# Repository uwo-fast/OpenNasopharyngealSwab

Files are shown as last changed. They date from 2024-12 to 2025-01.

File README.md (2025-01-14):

# Open Source Nasopharyngeal Swab and UV Curing System

This repository hosts the open-source design files, instructions, and validation results for a parametric nasopharyngeal swab and UV curing system. The designs are tailored for distributed manufacturing using accessible 3D printing technologies. Originally developed to address swab shortages during the COVID-19 pandemic, this project aims to provide a low-cost, scalable solution for clinical testing and other medical applications.

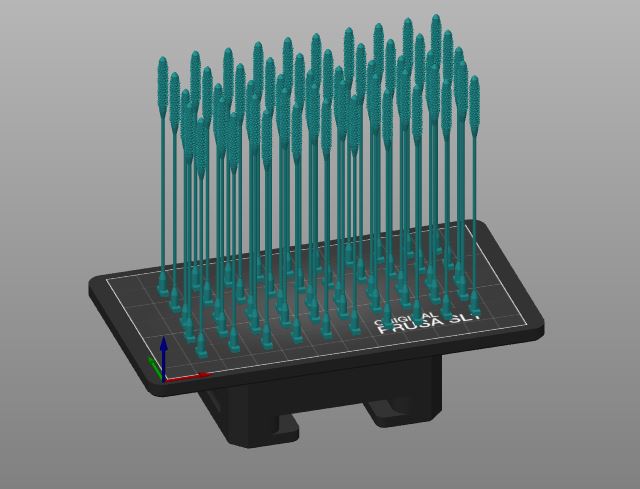
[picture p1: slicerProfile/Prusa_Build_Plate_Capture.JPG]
View of Swab on Build Plate in Slicer


## Features

- **Parametric Design:** Fully customizable in OpenSCAD to adapt swab and handle features for specific needs.
  - Tested with [github.com/CameronBrooks11/OpenSCAD-Batch-Export](https://github.com/CameronBrooks11/OpenSCAD-Batch-Export)
- **Distributed Manufacturing:** Designed for SLA 3D printers and modular UV curing systems, enabling local production with low-cost, accessible equipment.
- **Validated Performance:** Mechanical testing ensures durability and safety for clinical applications.
- **Open Source:** Licensed under GNU GPL v3.0 and CERN OHL v1.2 for maximum accessibility and collaboration.

## Cost Overview

- Nasopharyngeal Swabs:
  - Press-fit handle: ~$0.06/swab
  - Tong-style handle: ~$0.11/swab
- Modular UV Curing System: $45 total

## Included Components

1. **Swab Design Files:**
   - Parametric OpenSCAD files for the swab and handle.
   - STL files for SLA and FFF printers.
2. **UV Curing System:**
   - Design files for modular PCBs and 3D printable components.
   - Assembly instructions and parts list.

## Bill of Materials (BOM)

- **Swabs:** UV resin for swab heads and thermoplastics (e.g., PLA, PETG) for handles.
- **UV System:** Modular PCB components, UV LEDs, 3D printed brackets, and power supply.

## How to Use

### Swab Fabrication

1. Print swab heads using SLA 3D printers.
2. Print handles using FFF 3D printers.
3. Assemble and cure swabs in the UV curing system.

### UV Curing System Assembly

1. Solder PCBs and assemble the modular curing box.
2. Connect power and ensure system functionality with a multimeter.

### Validation

- Follow the provided mechanical testing protocols for tensile strength and break points.
- Conduct clinical testing in accordance with FDA or regional guidelines.

## Licensing

This project is licensed under:

- GNU General Public License (GPL) v3.0
- CERN Open Hardware License (OHL) v1.2

## Contributing

Contributions to improve the design, validation, or documentation are welcome. Please open an issue or submit a pull request.

## Citation

If you use this project in your work, please cite the original paper:  
Gallup, N., Pringle, A. M., Oberloier, S., Tanikella, N. G., & Pearce, J. M. (2020). *Parametric nasopharyngeal swab for sampling COVID-19 and other respiratory viruses: Open source design, SLA 3-D printing and UV curing system*. HardwareX, 8, e00135.

## Acknowledgments

This work was supported by the Witte Foundation and benefited from the contributions of numerous collaborators listed in the publication.

For more details, visit the [source paper](https://doi.org/10.1016/j.ohx.2020.e00135) or access original files on the [Open Science Framework (OSF)](https://osf.io/z5jgu/).

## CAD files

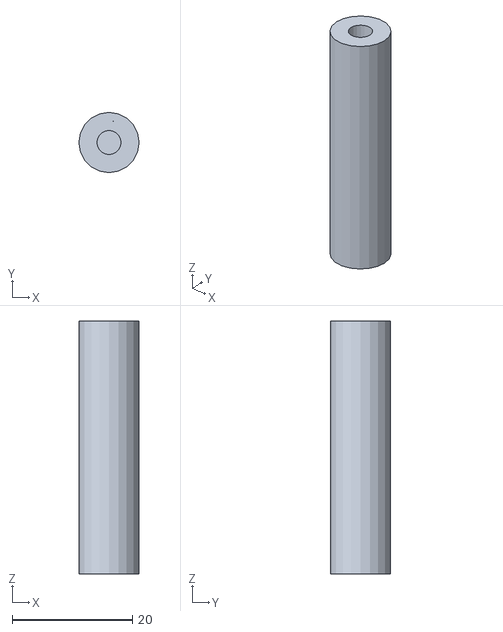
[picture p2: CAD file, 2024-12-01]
misc/durability_test_tube.stl
10.0 x 10.0 x 42.0

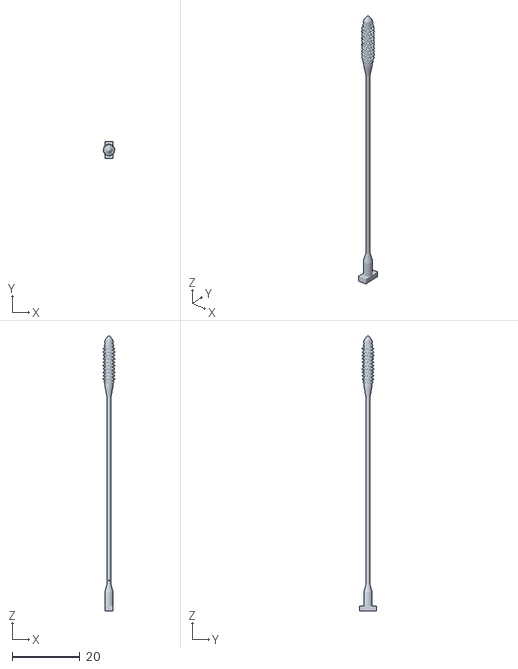
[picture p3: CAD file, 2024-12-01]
outputs/nasal_swab_bullet tip.stl
3.47 x 5.00 x 81.2

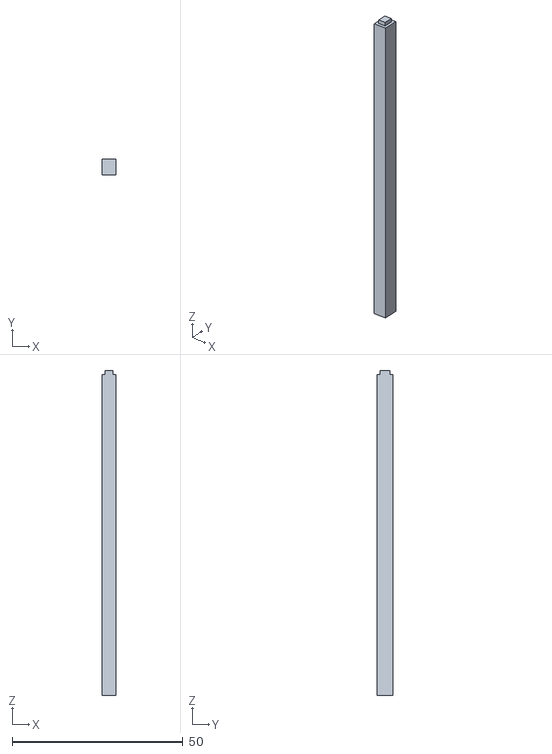
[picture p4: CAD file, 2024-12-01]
uvCuringBox/mech/legs.stl
4.00 x 4.70 x 95.1

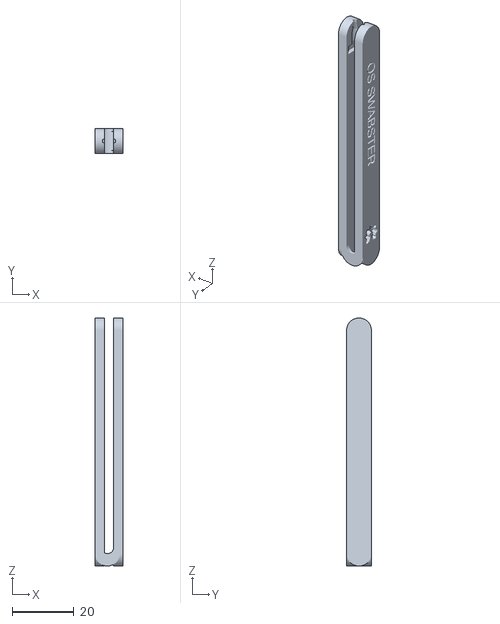
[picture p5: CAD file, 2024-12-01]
misc/tong_handle.stl
9.00 x 8.00 x 80.0

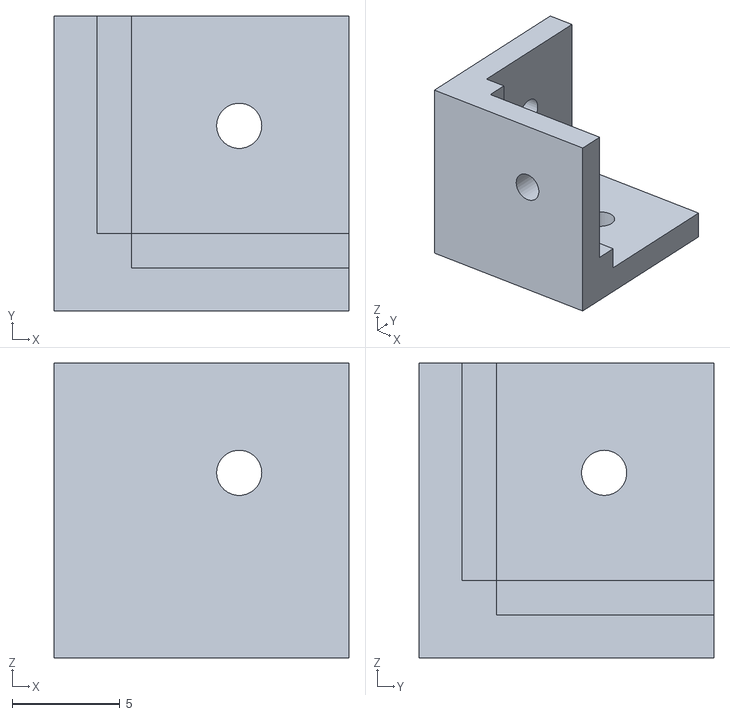
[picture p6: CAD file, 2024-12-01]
uvCuringBox/mech/corner.stl
13.7 x 13.7 x 13.7

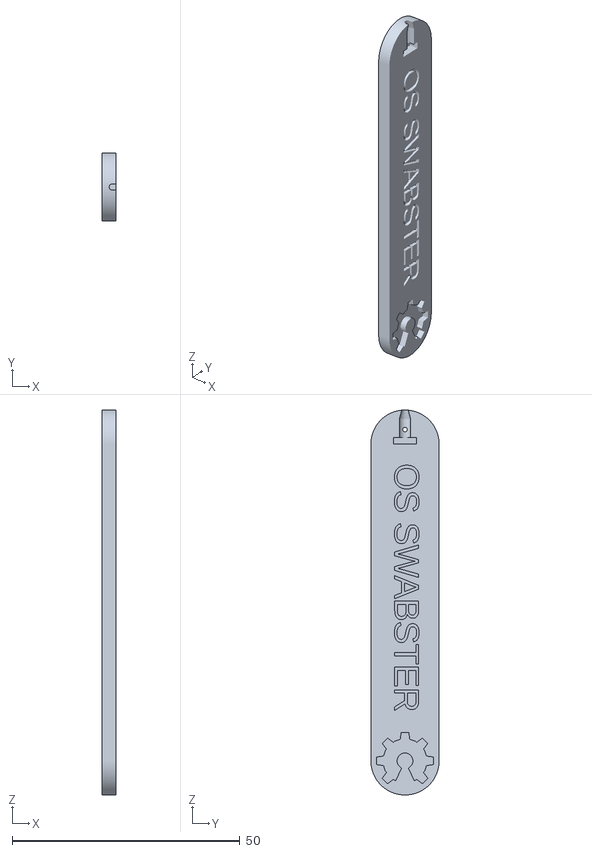
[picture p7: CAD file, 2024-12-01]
outputs/lock_handle.stl
3.00 x 15.0 x 84.5

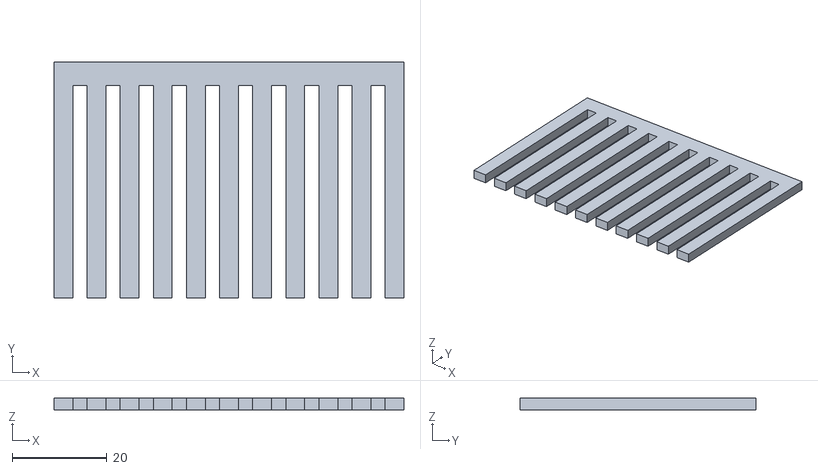
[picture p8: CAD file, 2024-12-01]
uvCuringBox/mech/top.stl
74.0 x 50.0 x 2.50

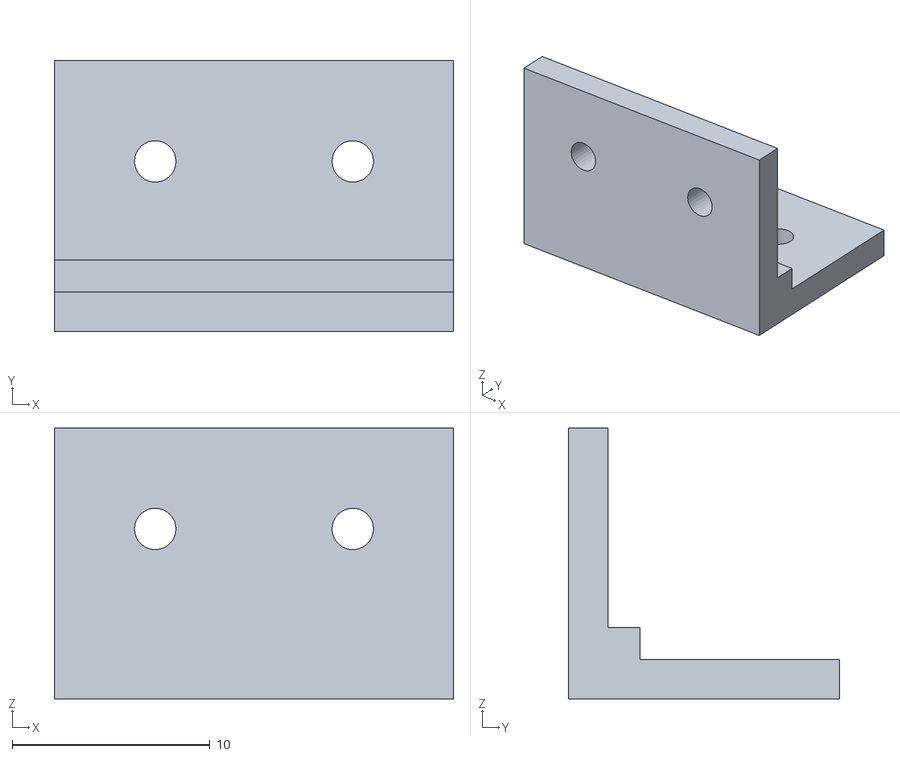
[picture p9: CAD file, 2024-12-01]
uvCuringBox/mech/edge.stl
20.2 x 13.7 x 13.7

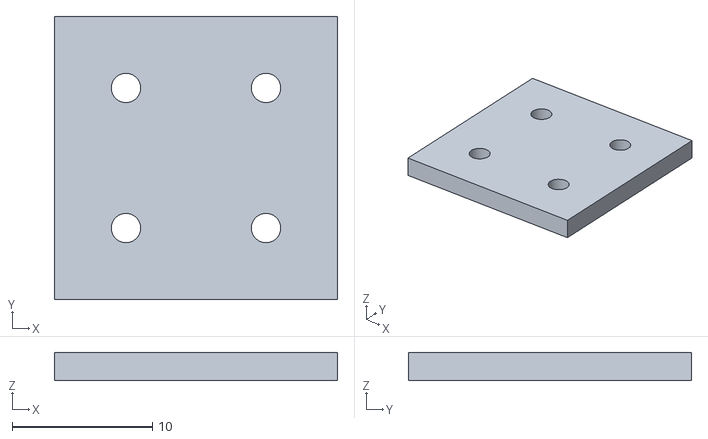
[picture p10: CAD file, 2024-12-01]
uvCuringBox/mech/plate.stl
20.2 x 20.2 x 2.00

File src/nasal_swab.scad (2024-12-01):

// OS nasal swab
// 20-4-21
// Adam Pringle
// MOST group at MTU
//
// Cameron K. Brooks
// Formatting and organizing
// FAST Research Group at UWO

// All units are in metric and mm unless otherwise specified

// Render the desired object by changing the name of the render variable
render = "nasal_swab"; // ["nasal_swab", "lock_handle", "both"]

// Tip type: Select the tip geometry type
tip_type = "bullet"; // ["bullet", "cone"]

if (render == "nasal_swab")
{
    nasal_swab();
}
else if (render == "lock_handle")
{
    lock_handle();
}
else if (render == "both")
{
    lock_handle();
    nasal_swab();
}

// Settings for contours and curve resolution
$fa = 0.5;  // minimum angle for a fragment,, recommended:0.5
$fs = 0.15; // minimum size of a fragment, recommended: 0.5 is for changing variables, 0.15 should be used for final
            // render

//[Tip settings] --------------------------------------------------------------------------------------------
tip_height = 16.25;  // Length of the tip height, recommended:16.25
tip_radius = 1.125;  // Radius of the tip body section, recommended:1.125

tip_arm_radius = 1.5;        // Max radius of the tip arms, recommended:1.5
tip_arm_thickness = .5;      // diameter of the tip arm cylinders, recommended:0.5
tip_arm_spread = .5;         // distance between layers of arms, recommended:0.5
tip_arm_count = 5;           // Number of arms per layer 360/count, recommended:3 or 5
tip_arm_rotation_angle = 90; // angle of rotation of arms layer to layer, recommended:90

tip_taper_low_height = 5; // Height of the taper region towards the body, recommended:5

tip_taper_top_height = 4; // Height of the taper region towards the top, recommended:4
tip_taper_top_R1 = 1;     // radius of top cylinder for subtraction at the top tip, recommended:1
tip_taper_bot_R2 = 1.5;   // radius of bot cylinder for subtraction at the top tip, recommended:1.5

// cone_tip
tip_point_height = 1.5;                // Height of the pointed section at the top of the tip, recommended:1
tip_point_radius_top = .25;            // radius of the top of the tip point, recommended:0.25
tip_point_radius_bot = tip_radius + 0; // radius of the bottom of the tip point, recommended:tip_radius+0.25

// bullet_tip
tip_point_radius_bullet = 1.15; // radius of the bullet tip, recommended:1.15

//[Body settings] --------------------------------------------------------------------------------------------
body_height = 55.5; // Height of the single-use body section, recommended:55.5
body_radius = 0.56; // radius of the single-use body section - match with base_taper_radius, recommended:0.56

body_breakpoint_radius = 0.175; // radius of the throughhole to ensure breaking at the weakpoint, recommended:0.1
body_breakpoint_height = 1;     // distance of breakpoint from the tapered section, recommended:1

//[base settings] --------------------------------------------------------------------------------------------
base_type = "lock";       //[spring, lock] select the base geometry type - only lock has been designed
base_height = 8;          // Height of the single-use body section, recommended:8
base_radius = 1.25;       // radius of the single-use body section, recommended:1.25
base_taper_radius = 0.56; // radius of the base taper - match with body_radius, recommended:0.56
base_taper_height = 2.5;  // length of the base height which tapers to the taper radius, recommended:2.5

base_flat_height =
    5; // length of the flat section on the bottom of the base use with spring base geometry, recommended:5
base_lock_length = 5;   // length of the L-shape locking mechanism, recommended:5
base_lock_height = 1.5; // height of the L-shape locking mechanism, recommended:1.5

//[handle settings] --------------------------------------------------------------------------------------------
handle_X_thickness = 1;             // thickness of handle under base insert in X direction, recommended:1
handle_X_width = base_radius + .75; // width of the handle section in total, recommended:base_radius+0.75
handle_Y_length = 15;               // length of the handle section, recommended:15
handle_Z_height = 85;               // handle height for gripping by people, recommended:85
handle_pin_hole_radius = .5;        // radius of the pinhole to ensure base is easy to pop, recommended:0.5

OSHW_logo_subtraction = 5;
OSHW_logo_diameter = 12.5;

handle_text_Z = -handle_Z_height * .05;
handle_text_Y = -handle_Y_length * .15;
handle_text_size = 5.5;
handle_text = "OS SWABSTER";

// module for construction of nasal_swab
module nasal_swab()
{
    color("yellow") if (tip_type == "cone")
    {

        cone_tip();
    }
    else if (tip_type == "bullet")
    {

        bullet_tip();
    }

    // color("purple")
    tip();

    color("blue") body();

    color("green") if (base_type == "spring")
    {

        spring_base();
    }
    else if (base_type == "lock")
    {

        lock_base();
    }
    // color("red")

} // end of module nasal_swab

module cone_tip()
{
    translate([ 0, 0, tip_height + tip_point_height / 2 + body_height + base_height ])
        cylinder(tip_point_height, tip_point_radius_bot, tip_point_radius_top, true);

} // end of module cone_tip

module bullet_tip()
{
    translate([ 0, 0, tip_height + tip_point_height / 2 + body_height + base_height ])

        hull()
    {
        translate([ 0, 0, tip_point_height / 2 - tip_point_radius_bullet / 2 ]) sphere(tip_point_radius_bullet / 2);

        translate([ 0, 0, -tip_point_height / 2 + tip_point_height * 0.1 ])
            cylinder(tip_point_height * 0.2, tip_point_radius_bot, tip_point_radius_bot, true);
    }
} // end of module bullet_tip

module tip()
{

    translate([ 0, 0, +body_height + base_height ])
    {

        difference()
        {
            color("purple") union()
            {
                translate([ 0, 0, tip_height / 2 ]) cylinder(tip_height, tip_radius, tip_radius, true);

                for (x = [tip_taper_low_height * .05:tip_height / (tip_arm_spread + tip_arm_thickness)]) // numb
                    translate([ 0, 0, (tip_arm_spread + tip_arm_thickness) * x - tip_arm_thickness / 2 ])
                        rotate([ 0, 0, 90 * x ]) for (x = [0:tip_height]) // # of arms on each layer
                        rotate([ 0, 0, 360 / tip_arm_count * x ])

                            hull()
                    {
                        translate([ tip_arm_radius, 0, 0 ]) sphere(tip_arm_thickness / 2);
                        translate([ -tip_arm_radius, 0, 0 ]) sphere(tip_arm_thickness / 2);
                    }
            }
            color("red")
                // top section taper towards tip tip
                translate([ 0, 0, tip_height ]) difference()
            {

                cylinder(tip_taper_top_height + .01, tip_arm_radius * 2 + .01, tip_arm_radius * 2 + .01, true);
                cylinder(tip_taper_top_height + .02, tip_taper_bot_R2, tip_taper_top_R1, true);
            }

            color("red")
                // bot section taper towards tip bottom
                translate([ 0, 0, tip_taper_low_height / 2 - tip_arm_thickness ]) difference()
            {

                cylinder(tip_taper_low_height + .01, tip_arm_radius * 2 + .01, tip_arm_radius * 2 + .01, true);
                cylinder(tip_taper_low_height + .02, body_radius, tip_arm_radius + .01, true);
            }
        }
    }
} // end of module tip

module spring_base() // bottom, blue section
{
    // taper section
    translate([ 0, 0, base_height / 2 + base_height / 2 - base_taper_height / 2 ])
        cylinder(base_taper_height, base_radius, base_taper_radius, true);

    // base section
    difference()
    {
        translate([ 0, 0, base_height / 2 - base_taper_height / 2 ])
            cylinder(base_height - base_taper_height, base_radius, base_radius, true);

        translate([ 0, base_radius, base_flat_height / 2 ])
            cube([ base_radius * 2, base_radius, base_flat_height + .01 ], true);
    }
} // end of module base

module lock_base() // bottom, blue section
{
    // taper section
    translate([ 0, 0, base_height / 2 + base_height / 2 - base_taper_height / 2 ])
        cylinder(base_taper_height, base_radius, base_taper_radius, true);

    // base section

    translate([ 0, 0, base_height / 2 - base_taper_height / 2 ])
        cylinder(base_height - base_taper_height, base_radius, base_radius, true);

    translate([ 0, 0, base_lock_height / 2 ]) cube([ base_radius * 2, base_lock_length, base_lock_height ], true);
}

module body()
{

    difference()
    {

        translate([ 0, 0, body_height / 2 + base_height ]) cylinder(body_height, body_radius, body_radius, true);

        translate([ 0, 0, 0 + base_height + body_breakpoint_height ]) rotate([ 90, 0, 0 ])
            cylinder(body_radius * 5, body_breakpoint_radius, body_breakpoint_radius, true, $fn = 15);
    }

} // end of module body
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

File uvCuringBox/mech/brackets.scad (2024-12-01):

p_tk = 2;
h_d = 2.1;
Off_X = 5;
Off_Y = 5;
b_tk = 1.6;

ext = 0.1;
$fn = 30;

module plate()
{
    translate([ 0, 0, -p_tk / 2 ]) difference()
    {
        translate([ -p_tk, -p_tk, 0 ]) cube([ (Off_X + h_d + 3) + p_tk, (Off_Y + h_d + 3) + p_tk, p_tk ]);
        translate([ Off_X, Off_Y, -ext ]) cylinder(h = p_tk + ext * 2, d = h_d);
    }
}

module p_1x2()
{
    plate();
    mirror([ 0, 1, 0 ]) plate();
}

module e_1x2()
{
    plate();
    translate([ 0, -p_tk / 2 - b_tk, p_tk / 2 + b_tk ]) rotate([ 90, 0, 0 ]) plate();
    translate([ -p_tk, -p_tk - b_tk, -p_tk / 2 ]) cube([ Off_X + h_d + 3 + p_tk, p_tk + b_tk, p_tk + b_tk ]);
}

module p_2x2()
{
    p_1x2();
    mirror([ 1, 0, 0 ]) p_1x2();
}

module e_2x2()
{
    e_1x2();
    mirror([ 1, 0, 0 ]) e_1x2();
}

module corner()
{
    plate();

    translate([ -p_tk / 2 - b_tk, 0, p_tk / 2 + b_tk ]) rotate([ 0, -90, 0 ]) plate();

    translate([ 0, -p_tk / 2 - b_tk, p_tk / 2 + b_tk ]) rotate([ 90, 0, 0 ]) plate();
    translate([ -p_tk, -p_tk - b_tk, -p_tk / 2 ]) cube([ Off_X + h_d + 3 + p_tk, p_tk + b_tk, p_tk + b_tk ]);
    translate([ -p_tk - b_tk, -p_tk, -p_tk / 2 ]) cube([ p_tk + b_tk, Off_X + h_d + 3 + p_tk, p_tk + b_tk ]);

    translate([ -p_tk - b_tk, -p_tk - b_tk, -p_tk / 2 ])
        cube([ p_tk + b_tk, p_tk + b_tk, Off_X + h_d + 3 + p_tk * 1 + b_tk ]);
}

e_2x2();

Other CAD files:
outputs/nasal_swab_cone_tip.stl

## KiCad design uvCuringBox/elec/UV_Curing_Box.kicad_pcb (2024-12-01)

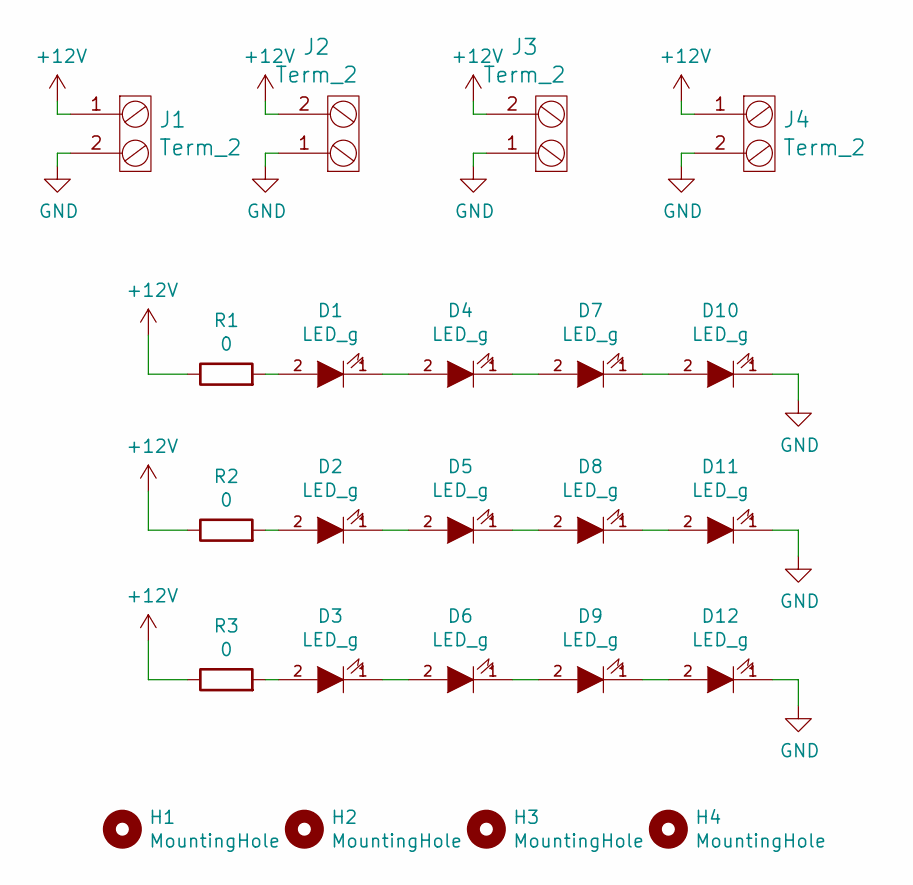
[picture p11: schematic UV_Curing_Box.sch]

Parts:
D1, D2, D3, D4, D5, D6, D7, D8, D9, D10, D11, D12: LED_g; LED-5MM; Part # C566C-GFF-CX0Y0892
H1, H2, H3, H4: MountingHole; MountingHole_2.2mm_M2
J1, J2, J3, J4: Term_2; TerminalBlock_Pheonix_MKDS1.5-2pol; Part # 1935161
R1, R2, R3: 0; R_1206_HandSoldering; Part # RC1206JR-070RL

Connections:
+12V: J1.1, J2.2, J3.2, J4.1, R1.1, R2.1, R3.1
GND: D10.1 (K), D11.1 (K), D12.1 (K), J1.2, J2.1, J3.1, J4.2
unnamed: D1.1 (K), D4.2 (A)
unnamed: D1.2 (A), R1.2
unnamed: D2.1 (K), D5.2 (A)
unnamed: D2.2 (A), R2.2
unnamed: D3.1 (K), D6.2 (A)
unnamed: D3.2 (A), R3.2
unnamed: D4.1 (K), D7.2 (A)
unnamed: D5.1 (K), D8.2 (A)
unnamed: D6.1 (K), D9.2 (A)
unnamed: D7.1 (K), D10.2 (A)
unnamed: D8.1 (K), D11.2 (A)
unnamed: D9.1 (K), D12.2 (A)

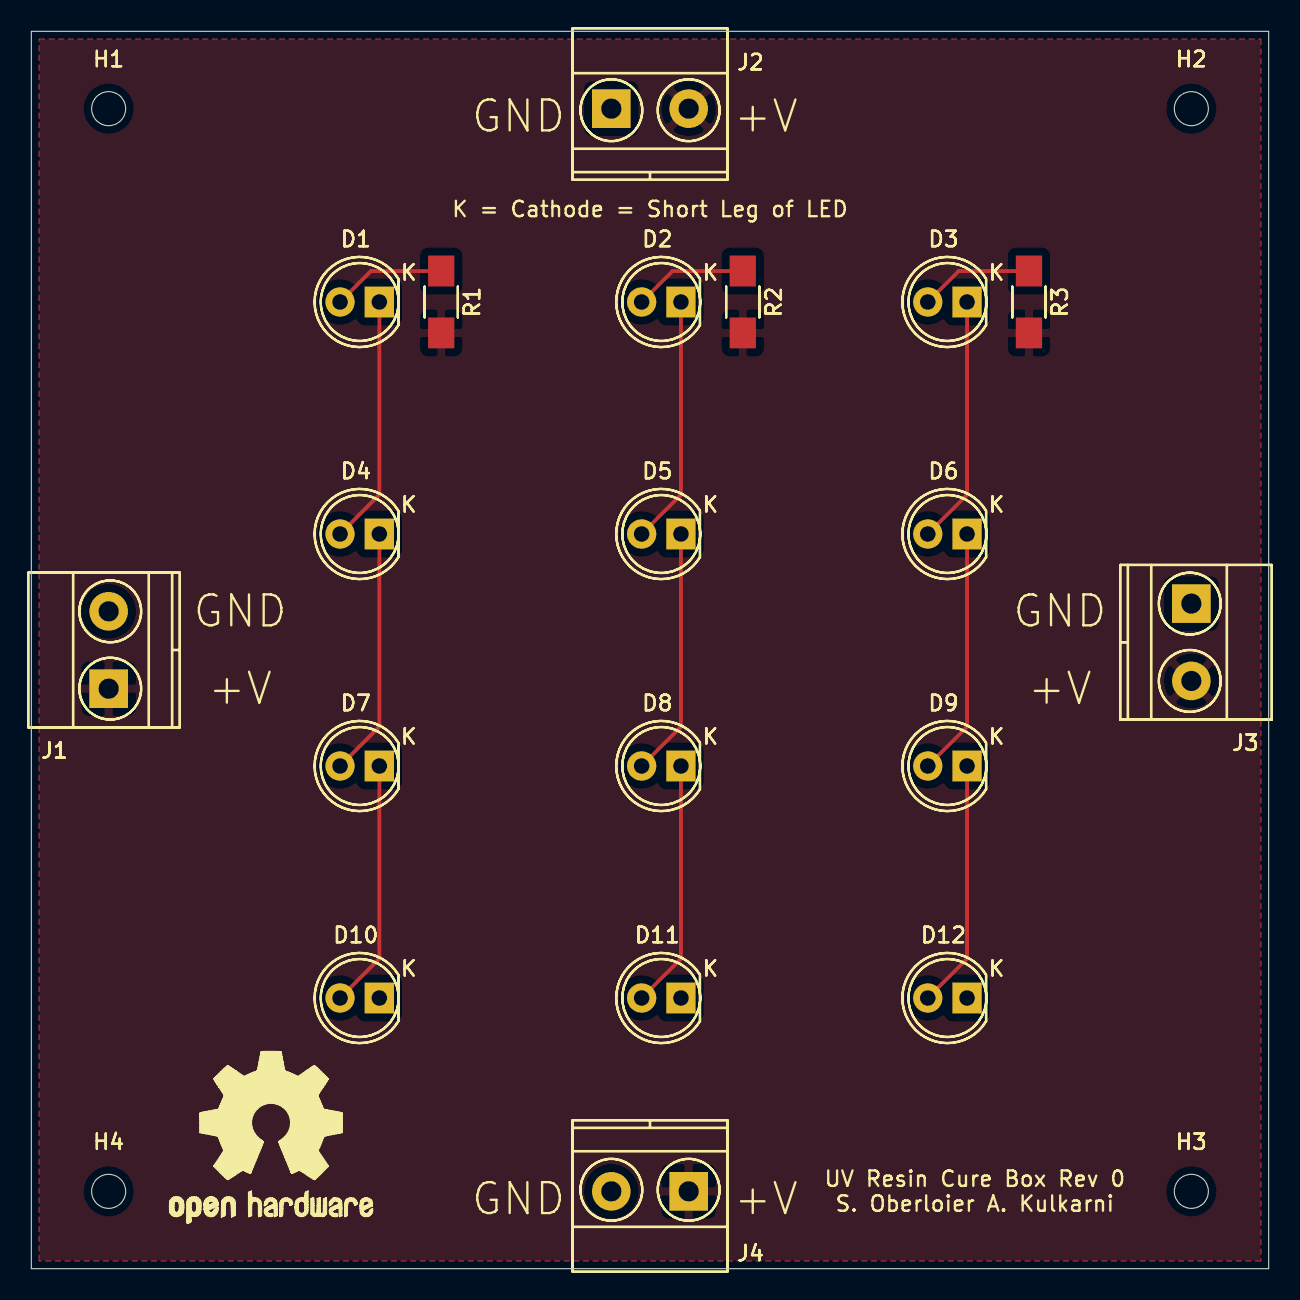
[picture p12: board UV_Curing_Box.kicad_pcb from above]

Board: 2 copper layers, 80.0 x 80.0 mm, 23 parts (0 on the bottom side), 14 nets.

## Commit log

2024-12-01 fixed depreciated use of assign()
    [nasal_swab.scad]
2024-12-01 updated to be compatible and test with OBE
    [Nasal Swab Durability Test Tube.stl, Nasal UV Curing Station Legs.stl, Nasal UV Curing Station Top.stl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]
